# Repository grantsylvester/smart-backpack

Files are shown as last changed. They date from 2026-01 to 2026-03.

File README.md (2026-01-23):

# Smart Backpack
## Description
This repository houses the software and PCB design for the Smart Backpack being created by Purdue ECE49595SD Team 10E. The two main directories are:

- PCB
    - This directory houses the KiCad project files for our PCB.
- Software
    - This directory houses the PlatformIO project that has the code to be flashed onto the ESP32.

## Software To Do List
This is a list of modules in the software that we need to implement still:

- **main.c**
    - Integrate all components to run the main program in this file

- **gps.c** and **gps.h**
    - src and header files for GPS-related functions

- **imu.c** and **imu.h**
    - src and header files for IMU-related functions

- **rfid.c** and **rfid.h**
    - src and header files for RFID reader-related functions

- **sensors.c** and **sensors.h**
    - src and header files for all other sensors:
        - Water bottle sensors
        - Laptop detection pressure switches
        - Zipper state hall effect sensors
        - Haptic feedback motors
        - Back Cooling Fan (stretch goal)

- **app.c** and **app.h**
    - src and header files for Bluetooth connection and the web application.

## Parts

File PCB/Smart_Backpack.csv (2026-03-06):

Reference | Qty | Value | DNP | Exclude from BOM | Exclude from Board | Footprint | Datasheet
C1,C8 | 2 | 22uF |  |  |  | Capacitor_SMD:C_1206_3216Metric_Pad1.33x1.80mm_HandSolder | https://mm.digikey.com/Volume0/opasdata/d220001/medias/docus/658/CL31A226KAHNNNE_Spec.pdf
C2,C5,C9,C10,C11,C14,C15 | 7 | 0.1uF |  |  |  | Capacitor_SMD:C_1206_3216Metric_Pad1.33x1.80mm_HandSolder | https://content.kemet.com/datasheets/KEM_C1002_X7R_SMD.pdf,https://mm.digikey.com/Volume0/opasdata/d220001/medias/docus/41/CL31B475KAHNNNE_Spec.pdf
C3 | 1 | 1uF |  |  |  | Capacitor_SMD:C_1206_3216Metric_Pad1.33x1.80mm_HandSolder | https://weblib.samsungsem.com/mlcc/mlcc-ec-data-sheet.do?partNumber=CL05Y105KP6VPN
C4 | 1 | 2.2nF |  |  |  | Capacitor_SMD:C_1206_3216Metric_Pad1.33x1.80mm_HandSolder | https://yageogroup.com/content/datasheet/asset/file/KEM_C1090_X7R_ESD
C6 | 1 | 10uF |  |  |  | Capacitor_SMD:C_1206_3216Metric_Pad1.33x1.80mm_HandSolder | https://mm.digikey.com/Volume0/opasdata/d220001/medias/docus/658/CL31A106KBHNNNE_Spec.pdf
C7 | 1 | 4.7uF |  |  |  | Capacitor_SMD:C_1206_3216Metric_Pad1.33x1.80mm_HandSolder | https://mm.digikey.com/Volume0/opasdata/d220001/medias/docus/41/CL31B475KAHNNNE_Spec.pdf
C12,C13 | 2 | 15pF |  |  |  | Capacitor_SMD:C_1206_3216Metric_Pad1.33x1.80mm_HandSolder | https://yageogroup.com/content/datasheet/asset/file/KEM_C1003_C0G_SMD
D1 | 1 | 3v3 Indicator |  |  |  | LED_SMD:LED_0603_1608Metric_Pad1.05x0.95mm_HandSolder | https://optoelectronics.liteon.com/upload/download/DS22-2000-226/LTST-S270KGKT.pdf
D2 | 1 | 5V Indicator |  |  |  | LED_SMD:LED_0603_1608Metric_Pad1.05x0.95mm_HandSolder | https://optoelectronics.liteon.com/upload/download/DS22-2000-226/LTST-S270KGKT.pdf
D3,D4 | 2 | ESD321 |  |  |  | Diode_SMD:D_01005_0402Metric_Pad0.57x0.30mm_HandSolder | https://www.ti.com/lit/ds/symlink/esd321.pdf?ts=1772214071851
H1,H2 | 2 | MountingHole |  | Excluded from BOM |  | MountingHole:MountingHole_2.2mm_M2 | ~
H3,H4,H5 | 3 | MountingHole |  | Excluded from BOM |  | MountingHole:MountingHole_3mm | ~
J1,J4,J5,J6 | 4 | Conn_01x03_Pin |  |  |  | Connector_JST:JST_VH_B3PS-VH_1x03_P3.96mm_Horizontal | https://www.jst-mfg.com/product/pdf/eng/eEH.pdf
J2,J3,J10 | 3 | Conn_01x02_Pin |  |  |  | Connector_JST:JST_VH_B2PS-VH_1x02_P3.96mm_Horizontal | https://www.jst-mfg.com/product/pdf/eng/eXH.pdf,~
J7 | 1 | Conn_01x07_Pin |  |  |  | Connector_JST:JST_VH_B7PS-VH_1x07_P3.96mm_Horizontal | https://www.jst-mfg.com/product/pdf/eng/eXH.pdf
J8 | 1 | Conn_01x08_Socket |  |  |  | Connector_PinHeader_2.54mm:PinHeader_1x08_P2.54mm_Vertical | ~
J9 | 1 | USB_C_Receptacle_USB2.0_16P |  |  |  | Connector_USB:USB_C_Receptacle_G-Switch_GT-USB-7010ASV | https://www.usb.org/sites/default/files/documents/usb_type-c.zip
L1 | 1 | 1uH |  |  |  | WeBench_Inductor:IND_BOURNS_SRN8040 | https://www.vishay.com/docs/34029/ilsb1206.pdf
R1 | 1 | 10 kΩ |  |  |  | Resistor_SMD:R_1206_3216Metric_Pad1.30x1.75mm_HandSolder | https://yageogroup.com/content/datasheet/asset/file/PYU-RT_1-TO-0-01_ROHS_L
R2 | 1 | 2kΩ |  |  |  | Resistor_SMD:R_1206_3216Metric_Pad1.30x1.75mm_HandSolder | https://yageogroup.com/content/datasheet/asset/file/PYU-RT_1-TO-0-01_ROHS_L
R3 | 1 | 22.1kΩ |  |  |  | Resistor_SMD:R_1206_3216Metric_Pad1.30x1.75mm_HandSolder | https://yageogroup.com/content/datasheet/asset/file/PYU-RT_1-TO-0-01_ROHS_L
R4,R5,R16 | 3 | 10kΩ |  |  |  | Resistor_SMD:R_1206_3216Metric_Pad1.30x1.75mm_HandSolder | https://yageogroup.com/content/datasheet/asset/file/PYU-RT_1-TO-0-01_ROHS_L
R6,R7,R8 | 3 | 10K |  |  |  | Resistor_SMD:R_1206_3216Metric_Pad1.30x1.75mm_HandSolder | https://yageogroup.com/content/datasheet/asset/file/PYU-RT_1-TO-0-01_ROHS_L
R9,R10,R12,R13 | 4 | 5.1kΩ |  |  |  | Resistor_SMD:R_1206_3216Metric_Pad1.30x1.75mm_HandSolder | https://yageogroup.com/content/datasheet/asset/file/PYU-RT_1-TO-0-01_ROHS_L
R11,R17 | 2 | 5Ω |  |  |  | Resistor_SMD:R_1206_3216Metric_Pad1.30x1.75mm_HandSolder | https://yageogroup.com/content/datasheet/asset/file/PYU-RT_1-TO-0-01_ROHS_L
R14 | 1 | 47.5kΩ |  |  |  | Resistor_SMD:R_1206_3216Metric_Pad1.30x1.75mm_HandSolder | https://yageogroup.com/content/datasheet/asset/file/PYU-RT_1-TO-0-01_ROHS_L
R15 | 1 | 1MΩ |  |  |  | Resistor_SMD:R_1206_3216Metric_Pad1.30x1.75mm_HandSolder | https://yageogroup.com/content/datasheet/asset/file/PYU-RT_1-TO-0-01_ROHS_L
R18 | 1 | 10MΩ |  |  |  | Resistor_SMD:R_1206_3216Metric_Pad1.30x1.75mm_HandSolder | https://yageogroup.com/content/datasheet/asset/file/PYU-RT_1-TO-0-01_ROHS_L
R19 | 1 | 150Ω |  |  |  | Resistor_SMD:R_1206_3216Metric_Pad1.30x1.75mm_HandSolder | https://yageogroup.com/content/datasheet/asset/file/PYU-RT_1-TO-0-01_ROHS_L
R20 | 1 | 330Ω |  |  |  | Resistor_SMD:R_1206_3216Metric_Pad1.30x1.75mm_HandSolder | https://yageogroup.com/content/datasheet/asset/file/PYU-RT_1-TO-0-01_ROHS_L
RTC1 | 1 | 32.768kHz |  |  |  | RTC:XTAL_AB38T-32.768KHZ-B7 | https://www.waldom.com/upload/parts/datasheets/mf-abr/abr-ab38t-32768khz.pdf
SW1,SW2 | 2 | SW_Push |  |  |  | SMD_Button:Shop_SMD_Button | https://www.citrelay.com/wp-content/uploads/2025/05/Switch-CS1102.pdf
U1 | 1 | TLV62569ADRL |  |  |  | Package_TO_SOT_SMD:SOT-563 | https://www.ti.com/lit/gpn/tlv62569a
U2 | 1 | MPU-6050 |  |  |  | IMU:QFN24_4X4X0P9-0P5_TDK-L | https://www.lcsc.com/datasheet/C24112.pdf
U3 | 1 | ESP32-PICO-MINI-02-N8R2 |  |  |  | STM32:ESP32-PICO-MINI-02_EXP | https://documentation.espressif.com/esp32-pico-mini-02_datasheet_en.pdf
U4 | 1 | CP2102N-Axx-xQFN28 |  |  |  | Package_DFN_QFN:QFN-28-1EP_5x5mm_P0.5mm_EP3.35x3.35mm | https://www.silabs.com/documents/public/data-sheets/cp2102n-datasheet.pdf

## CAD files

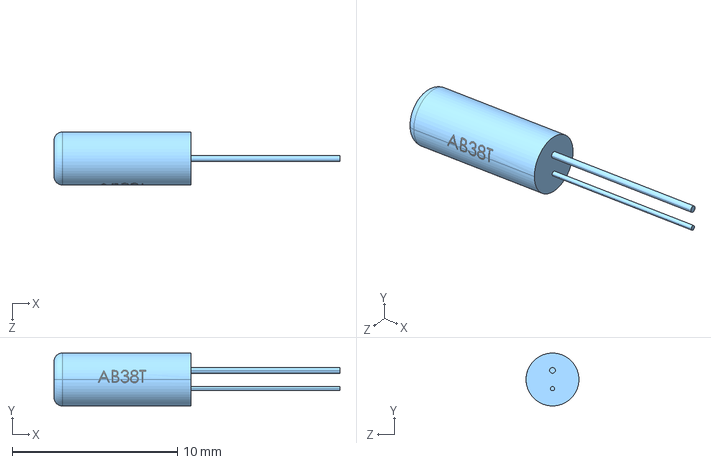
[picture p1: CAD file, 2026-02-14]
PCB/Custom Footprints/AB38T-32.768KHZ-B7.step
17.3 x 3.20 x 3.20 mm

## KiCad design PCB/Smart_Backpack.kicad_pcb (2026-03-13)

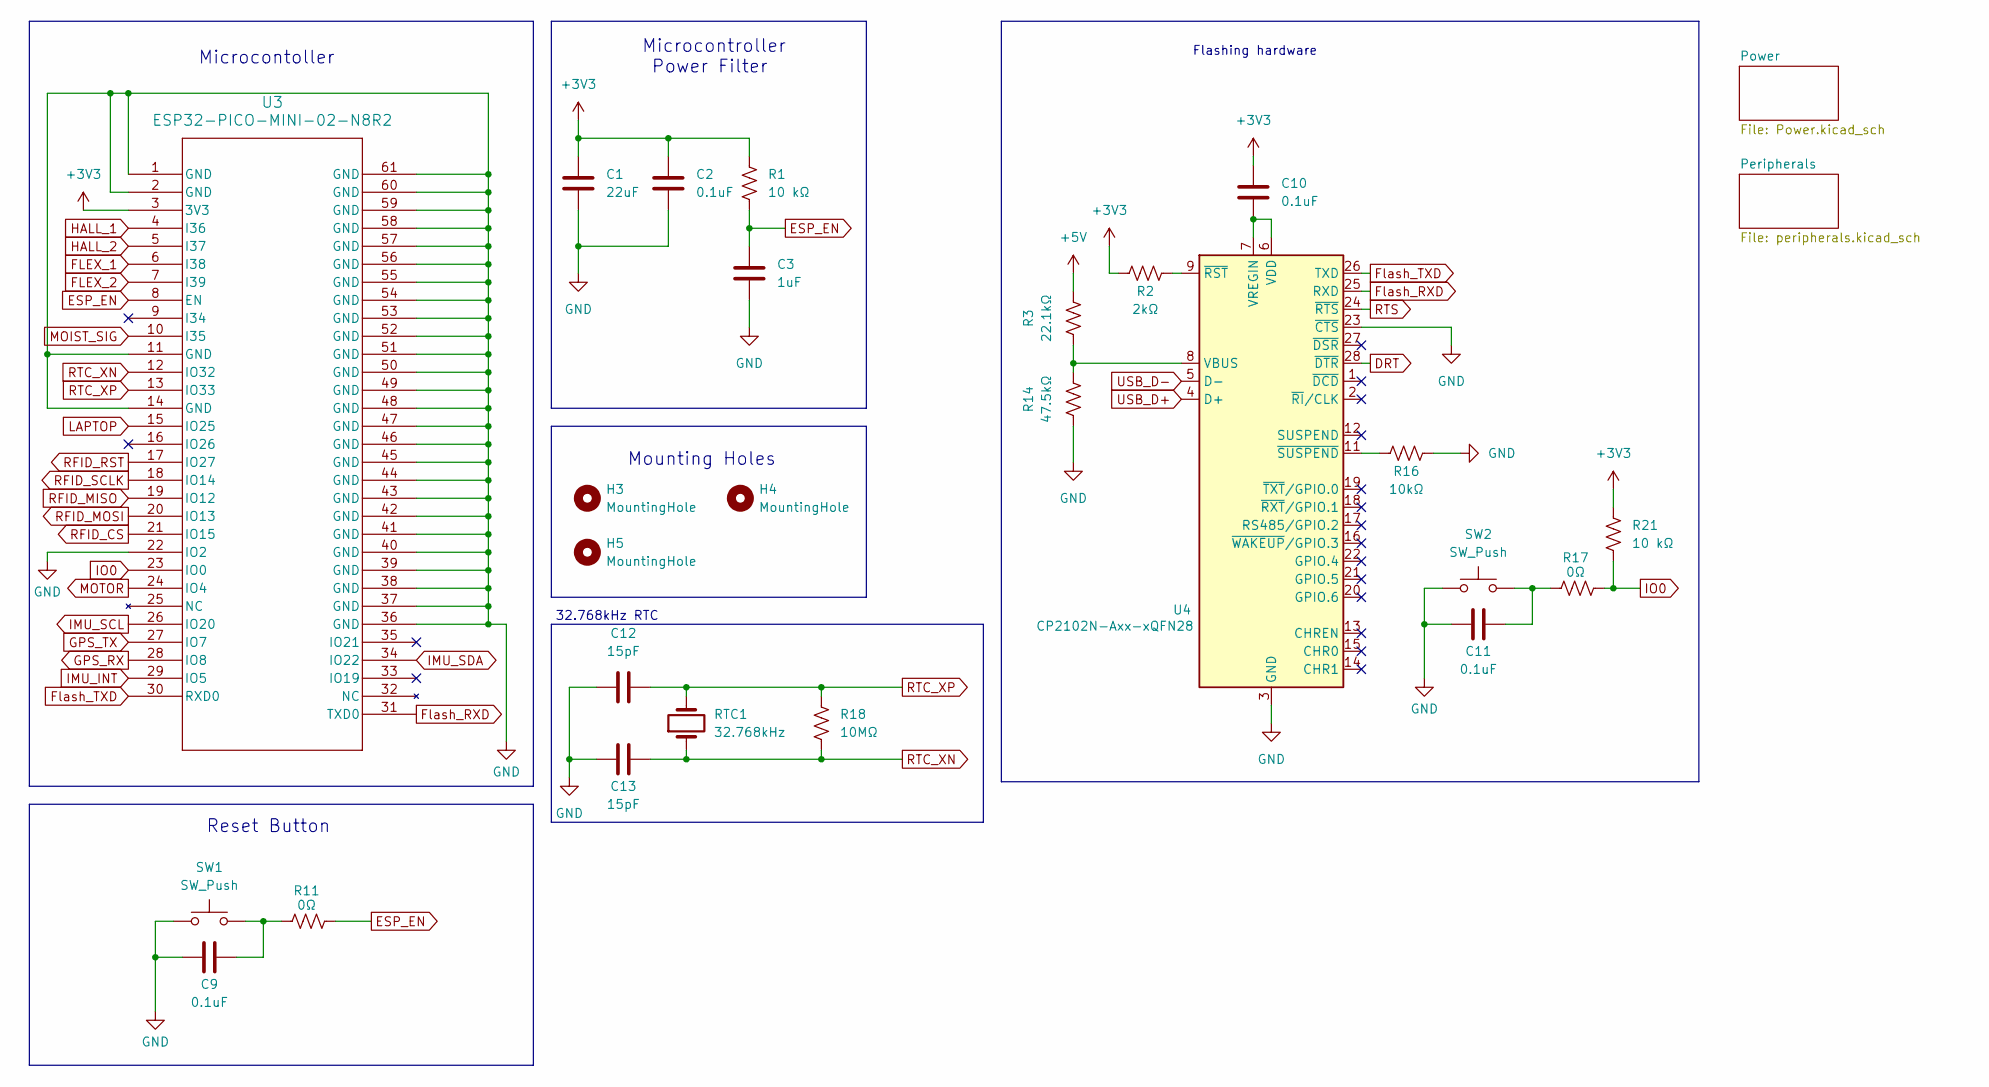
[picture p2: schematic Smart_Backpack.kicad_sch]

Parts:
C1: 22uF; C_1206_3216Metric_Pad1.33x1.80mm_HandSolder
C2, C9, C10, C11: 0.1uF; C_1206_3216Metric_Pad1.33x1.80mm_HandSolder
C3: 1uF; C_1206_3216Metric_Pad1.33x1.80mm_HandSolder
C12, C13: 15pF; C_1206_3216Metric_Pad1.33x1.80mm_HandSolder
H3, H4, H5: MountingHole; MountingHole_3mm
R1, R21: 10 kΩ; R_1206_3216Metric_Pad1.30x1.75mm_HandSolder
R2: 2kΩ; R_1206_3216Metric_Pad1.30x1.75mm_HandSolder
R3: 22.1kΩ; R_1206_3216Metric_Pad1.30x1.75mm_HandSolder
R11, R17: 0Ω; R_1206_3216Metric_Pad1.30x1.75mm_HandSolder
R14: 47.5kΩ; R_1206_3216Metric_Pad1.30x1.75mm_HandSolder
R16: 10kΩ; R_1206_3216Metric_Pad1.30x1.75mm_HandSolder
R18: 10MΩ; R_1206_3216Metric_Pad1.30x1.75mm_HandSolder
RTC1: 32.768kHz; XTAL_AB38T-32.768KHZ-B7
SW1, SW2: SW_Push; Shop_SMD_Button
U3: ESP32-PICO-MINI-02-N8R2; ESP32-PICO-MINI-02_EXP
U4: CP2102N-Axx-xQFN28; QFN-28-1EP_5x5mm_P0.5mm_EP3.35x3.35mm

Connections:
+3V3: C1.1, C2.1, C10.1, R1.1, R2.1, R21.1, U3.3 (3V3); also elsewhere on the board
+5V: R3.2; also elsewhere on the board
DRT: U4.28 (~DTR)
ESP_EN: C3.1, R1.2, R11.2, U3.8 (EN)
FLEX_1: U3.6 (I38); also elsewhere on the board
FLEX_2: U3.7 (I39); also elsewhere on the board
Flash_RXD: U3.31 (TXD0), U4.25 (RXD)
Flash_TXD: U3.30 (RXD0), U4.26 (TXD)
GND: C1.2, C2.2, C3.2, C9.2, C11.2, C12.1, C13.1, R14.1, R16.2, SW1.1, SW2.1, U3.1 (GND), U3.2 (GND), U3.11 (GND), U3.14 (GND), U3.22 (IO2), U3.36 (GND), U3.37 (GND), U3.38 (GND), U3.39 (GND), U3.40 (GND), U3.41 (GND), U3.42 (GND), U3.43 (GND), U3.44 (GND), U3.45 (GND), U3.46 (GND), U3.47 (GND), U3.48 (GND), U3.49 (GND), U3.50 (GND), U3.51 (GND), U3.52 (GND), U3.53 (GND), U3.54 (GND), U3.55 (GND), U3.56 (GND), U3.57 (GND), U3.58 (GND), U3.59 (GND), U3.60 (GND), U3.61 (GND), U4.3 (GND), U4.23 (~CTS), U4.29 (GND); also elsewhere on the board
GPS_RX: U3.28 (IO8); also elsewhere on the board
GPS_TX: U3.27 (IO7); also elsewhere on the board
HALL_1: U3.4 (I36); also elsewhere on the board
HALL_2: U3.5 (I37); also elsewhere on the board
IMU_INT: U3.29 (IO5); also elsewhere on the board
IMU_SCL: U3.26 (IO20); also elsewhere on the board
IMU_SDA: U3.34 (IO22); also elsewhere on the board
IO0: R17.2, R21.2, U3.23 (IO0)
LAPTOP: U3.15 (IO25); also elsewhere on the board
MOIST_SIG: U3.10 (I35); also elsewhere on the board
MOTOR: U3.24 (IO4); also elsewhere on the board
unnamed: C9.1, R11.1, SW1.2
unnamed: C11.1, R17.1, SW2.2
unnamed: R3.1, R14.2, U4.8 (VBUS)
unnamed: C10.2, U4.6 (VDD), U4.7 (VREGIN)
unnamed: R2.2, U4.9 (~RST)
unnamed: R16.1, U4.11 (~SUSPEND)
RFID_CS: U3.21 (IO15); also elsewhere on the board
RFID_MISO: U3.19 (IO12); also elsewhere on the board
RFID_MOSI: U3.20 (IO13); also elsewhere on the board
RFID_RST: U3.17 (IO27); also elsewhere on the board
RFID_SCLK: U3.18 (IO14); also elsewhere on the board
RTC_XN: C13.2, R18.2, RTC1.1, U3.12 (IO32)
RTC_XP: C12.2, R18.1, RTC1.2, U3.13 (IO33)
RTS: U4.24 (~RTS)
USB_D+: U4.4 (D+); also elsewhere on the board
USB_D-: U4.5 (D-); also elsewhere on the board

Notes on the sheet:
Mounting Holes
Microcontoller
32.768kHz RTC
Flashing hardware
Reset Button
Microcontroller Power Filter

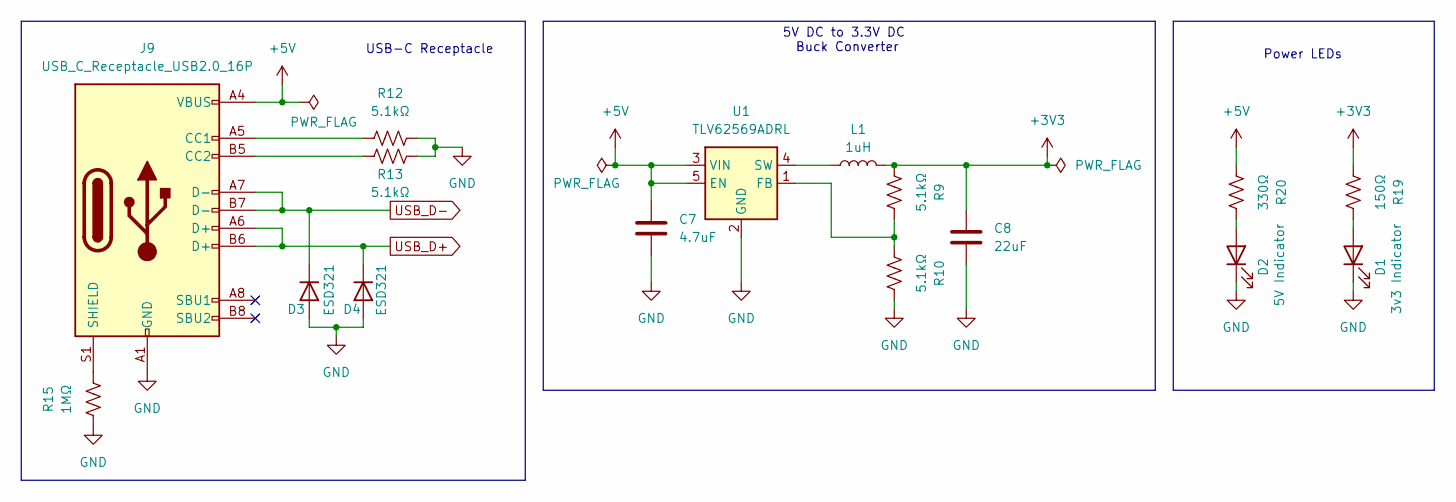
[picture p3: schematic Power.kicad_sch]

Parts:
C7: 4.7uF; C_1206_3216Metric_Pad1.33x1.80mm_HandSolder
C8: 22uF; C_1206_3216Metric_Pad1.33x1.80mm_HandSolder
D1: 3v3 Indicator; LED_0603_1608Metric_Pad1.05x0.95mm_HandSolder
D2: 5V Indicator; LED_0603_1608Metric_Pad1.05x0.95mm_HandSolder
D3, D4: ESD321; D_0402_1005Metric_Pad0.77x0.64mm_HandSolder
J9: USB_C_Receptacle_USB2.0_16P; USB_C_Receptacle_G-Switch_GT-USB-7010ASV
L1: 1uH; IND_BOURNS_SRN8040
R9, R10, R12, R13: 5.1kΩ; R_1206_3216Metric_Pad1.30x1.75mm_HandSolder
R15: 1MΩ; R_1206_3216Metric_Pad1.30x1.75mm_HandSolder
R19: 150Ω; R_1206_3216Metric_Pad1.30x1.75mm_HandSolder
R20: 330Ω; R_1206_3216Metric_Pad1.30x1.75mm_HandSolder
U1: TLV62569ADRL; SOT-563

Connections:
+3V3: C8.1, L1.2, R9.1, R19.1; also elsewhere on the board
+5V: C7.1, J9.A4 (VBUS), J9.A9 (VBUS), J9.B4 (VBUS), J9.B9 (VBUS), R20.1, U1.3 (VIN), U1.5 (EN); also elsewhere on the board
GND: C7.2, C8.2, D1.1 (K), D2.1 (K), D3.2 (A), D4.2 (A), J9.A1 (GND), J9.A12 (GND), J9.B1 (GND), J9.B12 (GND), R10.2, R12.2, R13.2, R15.1, U1.2 (GND); also elsewhere on the board
unnamed: D1.2 (A), R19.2
unnamed: D2.2 (A), R20.2
unnamed: J9.A5 (CC1), R12.1
unnamed: J9.B5 (CC2), R13.1
unnamed: J9.S1 (SHIELD), R15.2
unnamed: R9.2, R10.1, U1.1 (FB)
unnamed: L1.1, U1.4 (SW)
USB_D+: D4.1 (K), J9.A6 (D+), J9.B6 (D+); also elsewhere on the board
USB_D-: D3.1 (K), J9.A7 (D-), J9.B7 (D-); also elsewhere on the board

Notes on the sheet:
5V DC to 3.3V DC Buck Converter
Power LEDs
USB-C Receptacle

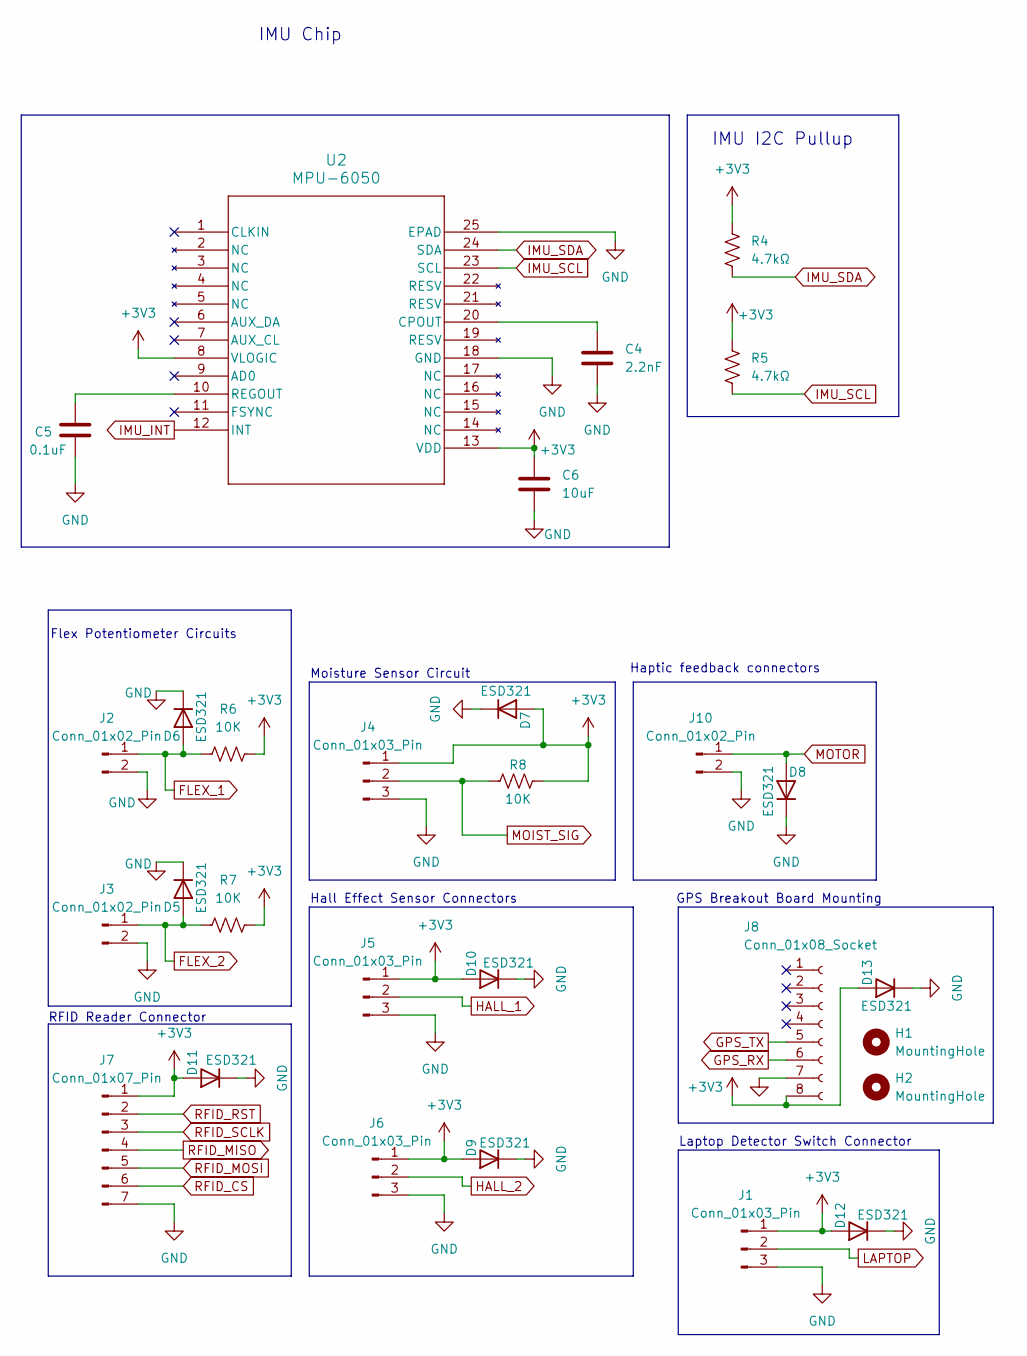
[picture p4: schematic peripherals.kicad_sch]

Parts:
C4: 2.2nF; C_1206_3216Metric_Pad1.33x1.80mm_HandSolder
C5: 0.1uF; C_1206_3216Metric_Pad1.33x1.80mm_HandSolder
C6: 10uF; C_1206_3216Metric_Pad1.33x1.80mm_HandSolder
D5, D6, D7, D8, D9, D10, D11, D12, D13: ESD321; D_0402_1005Metric_Pad0.77x0.64mm_HandSolder
H1, H2: MountingHole; MountingHole_2.2mm_M2
J1, J4, J5, J6: Conn_01x03_Pin; JST_VH_B3PS-VH_1x03_P3.96mm_Horizontal
J2, J3, J10: Conn_01x02_Pin; JST_VH_B2PS-VH_1x02_P3.96mm_Horizontal
J7: Conn_01x07_Pin; JST_VH_B7PS-VH_1x07_P3.96mm_Horizontal
J8: Conn_01x08_Socket; PinHeader_1x08_P2.54mm_Vertical
R4, R5: 4.7kΩ; R_1206_3216Metric_Pad1.30x1.75mm_HandSolder
R6, R7, R8: 10K; R_1206_3216Metric_Pad1.30x1.75mm_HandSolder
U2: MPU-6050; QFN24_4X4X0P9-0P5_TDK-L

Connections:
+3V3: C6.1, D7.2 (A), D9.2 (A), D10.2 (A), D11.2 (A), D12.2 (A), D13.2 (A), J1.1, J4.1, J5.1, J6.1, J7.1, J8.8, R4.1, R5.1, R6.2, R7.2, R8.2, U2.8 (VLOGIC), U2.13 (VDD); also elsewhere on the board
FLEX_1: D6.2 (A), J2.1, R6.1; also elsewhere on the board
FLEX_2: D5.2 (A), J3.1, R7.1; also elsewhere on the board
GND: C4.2, C5.2, C6.2, D5.1 (K), D6.1 (K), D7.1 (K), D8.1 (K), D9.1 (K), D10.1 (K), D11.1 (K), D12.1 (K), D13.1 (K), J1.3, J2.2, J3.2, J4.3, J5.3, J6.3, J7.7, J8.7, J10.2, U2.18 (GND), U2.25 (EPAD); also elsewhere on the board
GPS_RX: J8.6; also elsewhere on the board
GPS_TX: J8.5; also elsewhere on the board
HALL_1: J5.2; also elsewhere on the board
HALL_2: J6.2; also elsewhere on the board
IMU_INT: U2.12 (INT); also elsewhere on the board
IMU_SCL: R5.2, U2.23 (SCL); also elsewhere on the board
IMU_SDA: R4.2, U2.24 (SDA); also elsewhere on the board
LAPTOP: J1.2; also elsewhere on the board
MOIST_SIG: J4.2, R8.1; also elsewhere on the board
MOTOR: D8.2 (A), J10.1; also elsewhere on the board
unnamed: C4.1, U2.20 (CPOUT)
unnamed: C5.1, U2.10 (REGOUT)
RFID_CS: J7.6; also elsewhere on the board
RFID_MISO: J7.4; also elsewhere on the board
RFID_MOSI: J7.5; also elsewhere on the board
RFID_RST: J7.2; also elsewhere on the board
RFID_SCLK: J7.3; also elsewhere on the board

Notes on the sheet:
IMU I2C Pullup
Laptop Detector Switch Connector
GPS Breakout Board Mounting
RFID Reader Connector
Flex Potentiometer Circuits
Haptic feedback connectors
Moisture Sensor Circuit
Hall Effect Sensor Connectors
IMU Chip

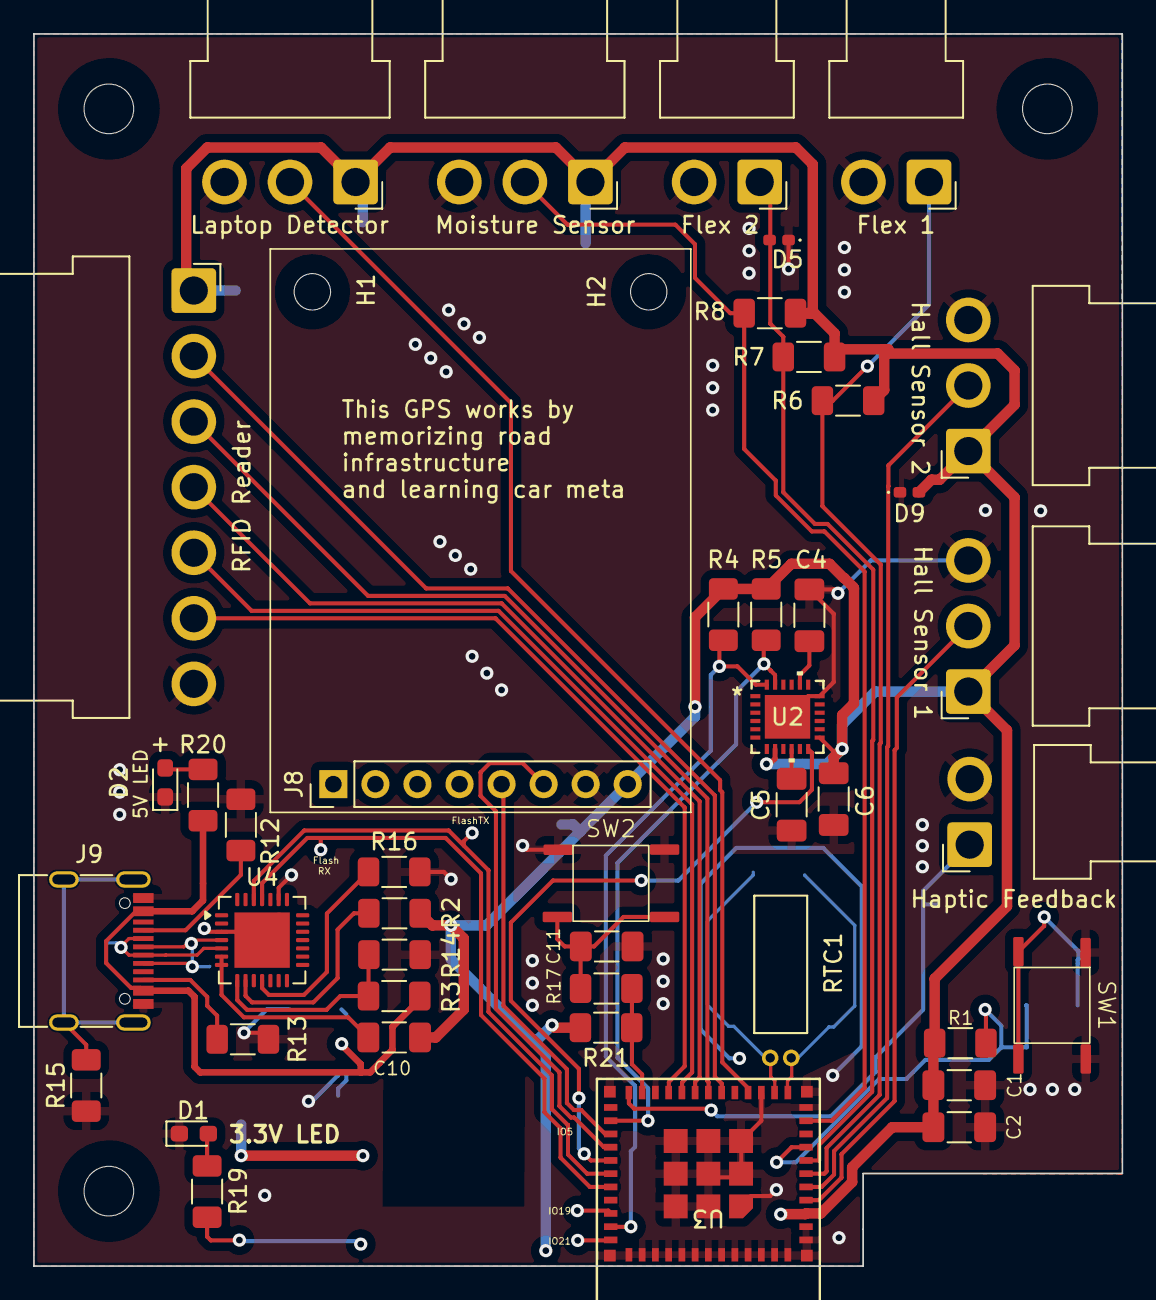
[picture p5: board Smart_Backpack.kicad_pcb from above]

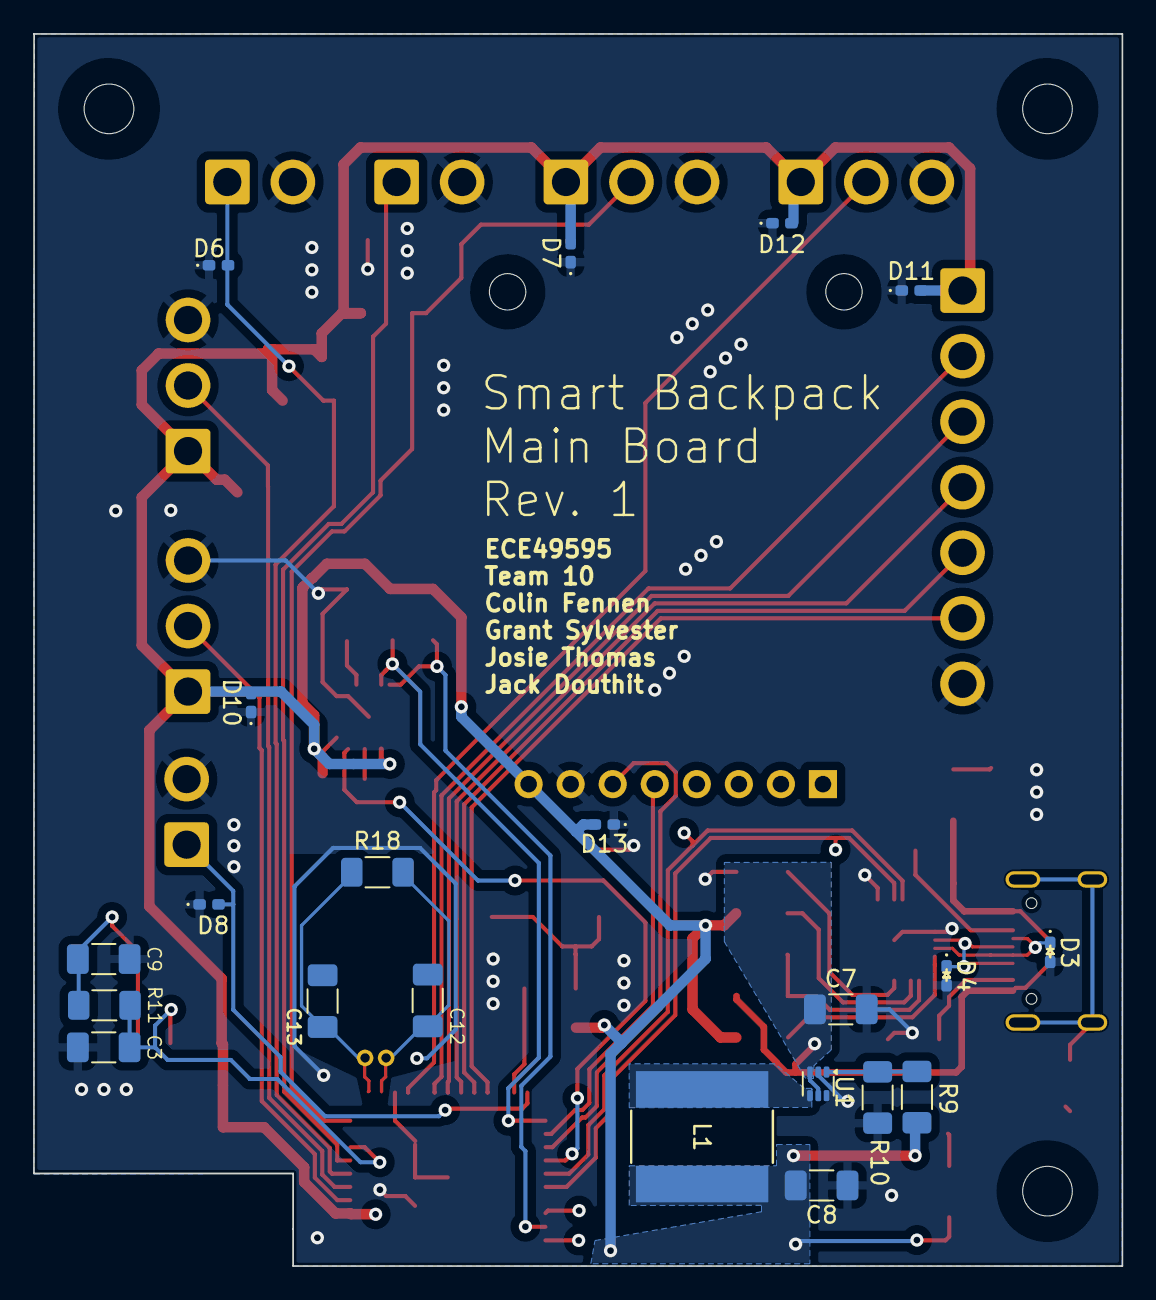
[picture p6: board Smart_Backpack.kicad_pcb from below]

Board: 2 copper layers, 65.8 x 74.4 mm, 70 parts (21 on the bottom side), 43 nets.

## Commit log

2026-01-22 create PCB folder
2026-01-23 Delete PCB/Smart Backpack PCB-backups directory
    I'm dumb and can just add the folder
2026-01-23 Delete PCB/Smart_Backpack-Backups directory
    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
2026-01-23 jack test
    [Smart_Backpack.kicad_sch]
2026-01-23 Delete PCB/untitled.kicad_sch
    I hate this software
    [untitled.kicad_sch]
2026-01-26 Added IMU footprint/symbol
    [Smart_Backpack.kicad_pcb, Smart_Backpack.kicad_sch, untitled.kicad_sch]
2026-01-26 update todo list
    [Smart_Backpack.kicad_sch]
2026-01-27 New IMU symbol/footprint
    [Smart_Backpack.kicad_pcb, untitled.kicad_sch]
2026-01-27 Just changed some ground pins to ground
    [Smart_Backpack.kicad_sch]
2026-01-27 Added micro footprint
    [Smart_Backpack.kicad_pcb, Smart_Backpack.kicad_sch]
2026-01-28 work on IMU
    [Smart_Backpack.kicad_sch, untitled.kicad_sch]
2026-01-29 IMU done yay
    [Power.kicad_sch, Smart_Backpack.kicad_sch, untitled.kicad_sch]
2026-01-31 add connectors for off-board components
    [untitled.kicad_sch]
2026-02-06 She buck on my converter till I 3.3V DC
    [Power.kicad_sch, untitled.kicad_sch]
2026-02-07 add pressure button and R, C, and L footprints
    [Power.kicad_sch, Smart_Backpack.kicad_pcb, Smart_Backpack.kicad_sch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]
2026-02-07 Work on adding on board flashing
    [Power.kicad_sch, Smart_Backpack.kicad_sch]
2026-02-09 Updated to-do list
    [Smart_Backpack.kicad_sch]
2026-02-10 Created push button footprint
    [Power.kicad_sch, Smart_Backpack.kicad_sch]
2026-02-10 Added IO0 button
    [Power.kicad_sch, Smart_Backpack.kicad_sch]
2026-02-11 add RTC and TX/RX signals
    [Smart_Backpack.kicad_sch, peripherals.kicad_sch]
2026-02-12 add power indicator LEDs, connect peripherals
    [Power.kicad_sch, Smart_Backpack.kicad_sch, peripherals.kicad_sch]
2026-02-14 lots of 'final' schematic updates. ERC is essentially clean, PCB design can begin
    [AB38T-32.768KHZ-B7.step, Power.kicad_sch, Smart_Backpack.kicad_pcb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]
2026-02-14 Created BOM and added USBC footprint
    [Power.kicad_sch, Smart_Backpack.csv, Smart_Backpack.kicad_sch]
2026-02-15 Finally PCB progress
    [Smart_Backpack.kicad_pcb]
2026-02-16 bit more PCB progress, added buttons and filter
    [Smart_Backpack.kicad_pcb]
2026-02-16 route IMU, fix MCU orientation, space GPS mounting
    [Smart_Backpack.kicad_pcb]
2026-02-17 place and route connectors, add edges
    [Smart_Backpack.kicad_pcb, Smart_Backpack.kicad_sch, peripherals.kicad_sch]
2026-02-17 PCB revision 1 is finished!!!!
    [Smart_Backpack.kicad_pcb]
2026-02-17 add ground vias, RTC protection, and mounting hole exclusion zones
    [Smart_Backpack.kicad_pcb]
2026-02-17 Some updates suggested by Ryan (The 1 sem senior design prof)
    [Power.kicad_sch, Smart_Backpack.kicad_pcb, Smart_Backpack.kicad_sch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]
2026-02-18 Literally just added our names
    [Smart_Backpack.kicad_pcb]
2026-02-18 Added motors :pensive:
    [Smart_Backpack.kicad_pcb, Smart_Backpack.kicad_sch, peripherals.kicad_sch]
2026-02-18 add datasheets to schematic and silkscreen board label
    [Power.kicad_sch, Smart_Backpack.kicad_pcb, Smart_Backpack.kicad_sch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]
2026-02-18 fix silkscreen for motor connector
    [Smart_Backpack.kicad_pcb]
2026-02-24 Alert: Fat inductor incoming
    [Power.kicad_sch, Smart_Backpack.kicad_pcb, Smart_Backpack.kicad_sch]
2026-02-25 fix edge cuts and route IMU_INT
    [Smart_Backpack.kicad_pcb, Smart_Backpack.kicad_sch]
2026-02-27 add esd protection and buck caps and move USB-C over edge
    [Power.kicad_sch, Smart_Backpack.kicad_pcb]
2026-03-03 PCB hopefully finished
    [Smart_Backpack.kicad_pcb]
2026-03-06 fix esd diode footprints
    [Power.kicad_sch, Smart_Backpack.csv, Smart_Backpack.kicad_pcb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]
2026-03-06 Fixed all DRC
    [Smart_Backpack.kicad_pcb]
2026-03-06 Generated Gerbers
    [Smart_Backpack-B_Cu.gbl, Smart_Backpack-B_Mask.gbs, Smart_Backpack-B_Paste.gbp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]
2026-03-07 Start of feedback implementation
    [Power.kicad_sch, Smart_Backpack.kicad_pcb, Smart_Backpack.kicad_sch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]
2026-03-07 Implemented all feedback except buck converter
    [Smart_Backpack.kicad_pcb, peripherals.kicad_sch]
2026-03-08 This time for sure...
    [Smart_Backpack.kicad_pcb, Smart_Backpack.kicad_sch]
2026-03-09 add new feedback
    [Smart_Backpack.kicad_pcb]
2026-03-09 add one singular via
    [Smart_Backpack.kicad_pcb]
2026-03-10 fix power layout again
    [Smart_Backpack.kicad_pcb]
2026-03-13 PCB finished and ordered
    [Smart_Backpack-B_Cu.gbl, Smart_Backpack-B_Mask.gbs, Smart_Backpack-B_Paste.gbp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]
